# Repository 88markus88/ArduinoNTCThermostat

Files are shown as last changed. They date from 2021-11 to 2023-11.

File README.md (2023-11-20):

# ArduinoNTCThermostat
This project is an Arduino based Thermostat for universal use. I put it together rather quick&dirty since I needed a simple thermostat, and I could not find one that fit my needs...
The project contains the Arduino code and the KiCad files for the board.

I ended up with a rather generic setup, that may be of use to others. The thermostat is intended to be used standalone in 12V or 24 V environments. It's settings for cooling or heating mode, for the target temperature and the hysteresis can be set without recompilation using a bridge (heating/cooling) and DIP switches (target temperature and hysteresis). A relay is fitted that can switch up to 250V and 10A.
A SSD1306 compatible OLED display can be fitted as an option to display detailed information.

## Features:
- Temperature measurement is done via a 10K NTC sensor
- Powered using an efficient DCDC converter (Traco TSR 1-2450E pin compatible to 7805) for operation in range of 7-36 V DC. The thermostat can easily operate in 12 or 24 V installations.
- Set for heating or cooling operation with a bridge
- Set target temperature fron 0 to 254 °C in 2°C steps via DIP switches
- Set hysteresis from 0 to 14 °C in 2°C steps via DIP switches
- 250V 10A relay. PCB design supports up to 10 A
- 2 LEDs: power indicator and switch indicator
- Optional OLED display via I2C

## PCB
The PCB has been designed in Kicad. Kicad files are included in this repository, also the Gerber files that can directly be used to order the PCBs

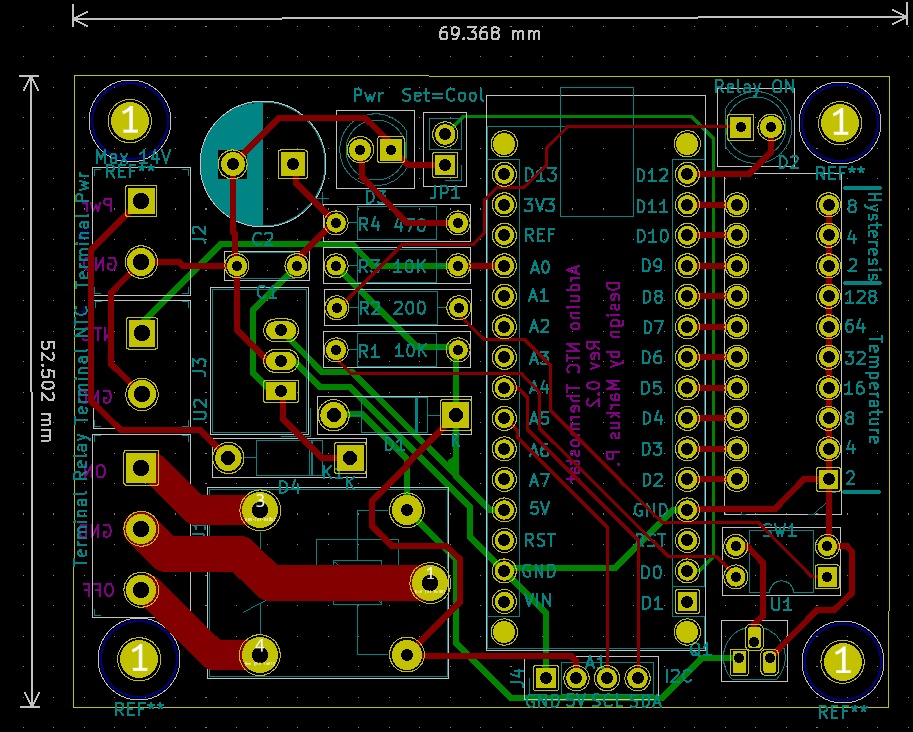
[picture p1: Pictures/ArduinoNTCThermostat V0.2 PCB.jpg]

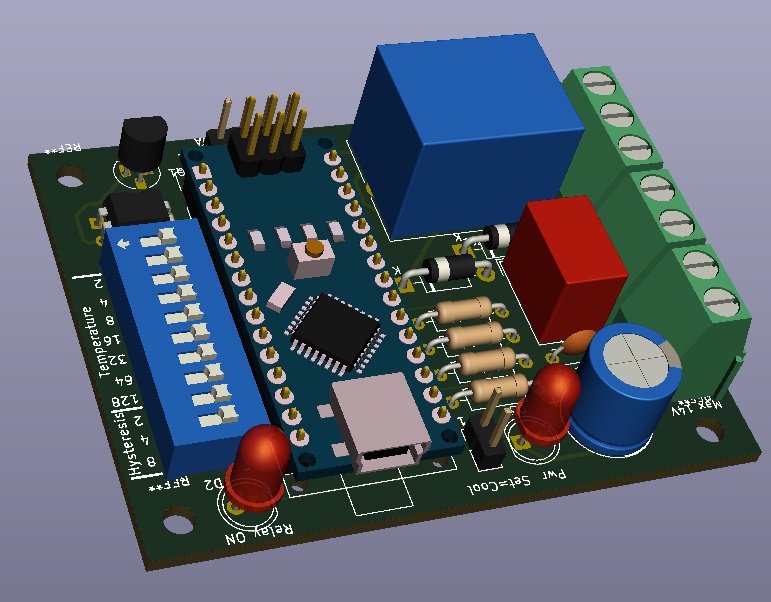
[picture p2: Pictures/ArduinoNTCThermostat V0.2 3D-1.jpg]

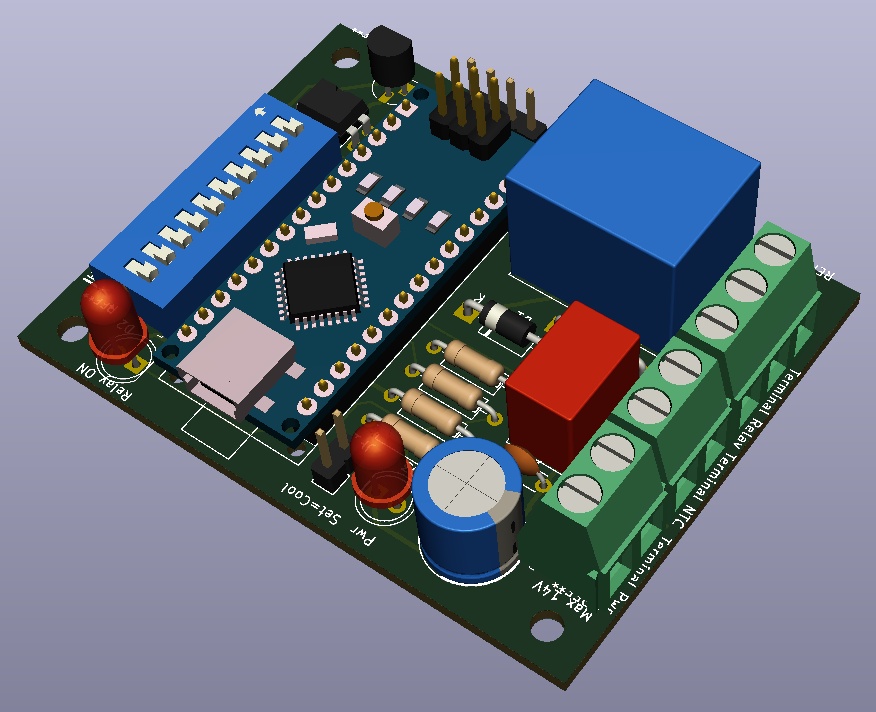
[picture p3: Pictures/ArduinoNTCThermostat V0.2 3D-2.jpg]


## Parts List
- PCB: Gerber files are attached
- Arduino Pro Micro (with socket, if desired)
- Transistor BC547
- Electrolyte Capacitor 47 uF / 25V
- Tantal Capacitor 100 nF
- Opto Coupler LTV 817
- 2 Diodes 1N4001 or 1N4004
- 2 LEDs
- Power via DCDC  Traco TSR 1-2450E, alternatively 7850
- 10x DIP Switch
- Screw Terminals 5.08 mm pitch: 2x 2, 1x 3 connections
- Relay Songle SRD-05VDC-SL-C
- Resistors: 200, 470 and 2 x 10K Ohm
- NTC 10K
- OLED Display with SSD1306 controller (optional)
- Housing

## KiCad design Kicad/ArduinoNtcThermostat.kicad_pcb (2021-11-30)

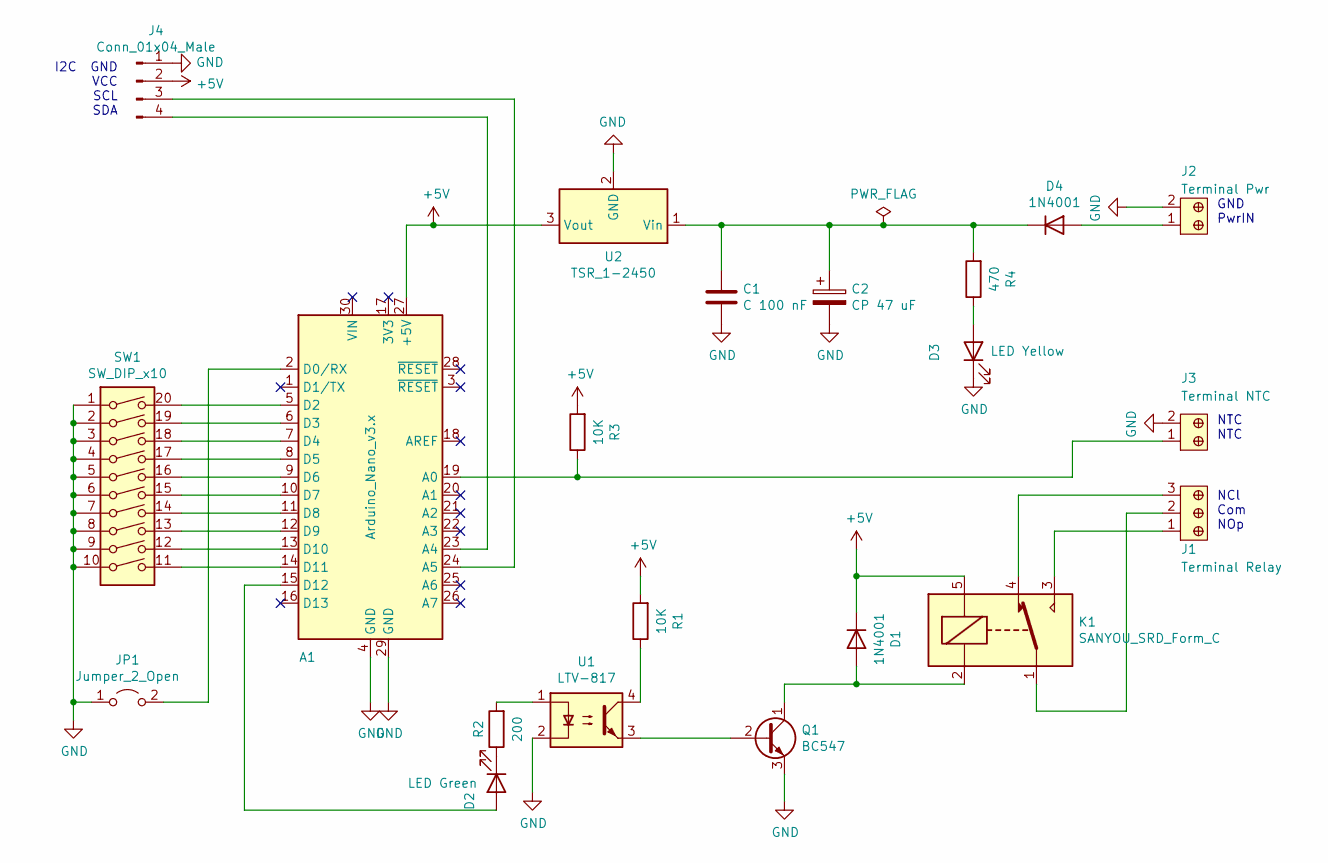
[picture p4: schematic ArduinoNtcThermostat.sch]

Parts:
A1: Arduino_Nano_v3.x; Arduino_Nano_WithMountingHoles
C1: C 100 nF; C_Disc_D4.3mm_W1.9mm_P5.00mm
C2: CP 47 uF; CP_Radial_D10.0mm_P5.00mm
D1, D4: 1N4001; D_DO-41_SOD81_P10.16mm_Horizontal
D2: LED Green; LED_D5.0mm
D3: LED Yellow; LED_D5.0mm
J1: Terminal Relay; TERM_BLOCK_1x3_P5.08MM; MPN OSTTC032162; Digi-Key_PN ED2610-ND
J2: Terminal Pwr; Term_Block_1x2_P5.08MM; MPN OSTTC022162; Digi-Key_PN ED2609-ND
J3: Terminal NTC; Term_Block_1x2_P5.08MM; MPN OSTTC022162; Digi-Key_PN ED2609-ND
J4: Conn_01x04_Male; PinHeader_1x04_P2.54mm_Vertical
JP1: Jumper_2_Open; PinHeader_1x02_P2.54mm_Vertical
K1: SANYOU_SRD_Form_C; Relay_SPDT_SANYOU_SRD_Series_Form_C
Q1: BC547; TO-92_HandSolder
R1, R3: 10K; R_Axial_DIN0207_L6.3mm_D2.5mm_P10.16mm_Horizontal
R2: 200; R_Axial_DIN0207_L6.3mm_D2.5mm_P10.16mm_Horizontal
R4: 470; R_Axial_DIN0207_L6.3mm_D2.5mm_P10.16mm_Horizontal
SW1: SW_DIP_x10; DIP-20_W7.62mm
U1: LTV-817; DIP-4_W7.62mm
U2: TSR_1-2450; Converter_DCDC_TRACO_TSR-1_THT

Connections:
+5V: A1.27 (+5V), D1.1 (K), J4.2, K1.5, R1.2, R3.2, U2.3 (Vout)
GND: A1.4 (GND), A1.29 (GND), C1.2, C2.2, D3.1 (K), J2.2, J3.2, J4.1, JP1.1 (A), Q1.3 (E), SW1.1, SW1.2, SW1.3, SW1.4, SW1.5, SW1.6, SW1.7, SW1.8, SW1.9, SW1.10, U1.2, U2.2 (GND)
unnamed: A1.2 (D0/RX), JP1.2 (B)
unnamed: A1.5 (D2), SW1.20
unnamed: A1.6 (D3), SW1.19
unnamed: A1.7 (D4), SW1.18
unnamed: A1.8 (D5), SW1.17
unnamed: A1.9 (D6), SW1.16
unnamed: A1.10 (D7), SW1.15
unnamed: A1.11 (D8), SW1.14
unnamed: A1.12 (D9), SW1.13
unnamed: A1.13 (D10), SW1.12
unnamed: A1.14 (D11), SW1.11
unnamed: A1.15 (D12), D2.2 (A)
unnamed: A1.19 (A0), J3.1, R3.1
unnamed: A1.23 (A4), J4.4
unnamed: A1.24 (A5), J4.3
unnamed: C1.1, C2.1, D4.1 (K), R4.2, U2.1 (Vin)
unnamed: D1.2 (A), K1.2, Q1.1 (C)
unnamed: D2.1 (K), R2.1
unnamed: D3.2 (A), R4.1
unnamed: D4.2 (A), J2.1
unnamed: J1.1, K1.3
unnamed: J1.2, K1.1
unnamed: J1.3, K1.4
unnamed: Q1.2 (B), U1.3
unnamed: R1.1, U1.4
unnamed: R2.2, U1.1

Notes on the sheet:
I2C GND VCC SCL SDA
NCl Com NOp
NTC NTC
GND PwrIN

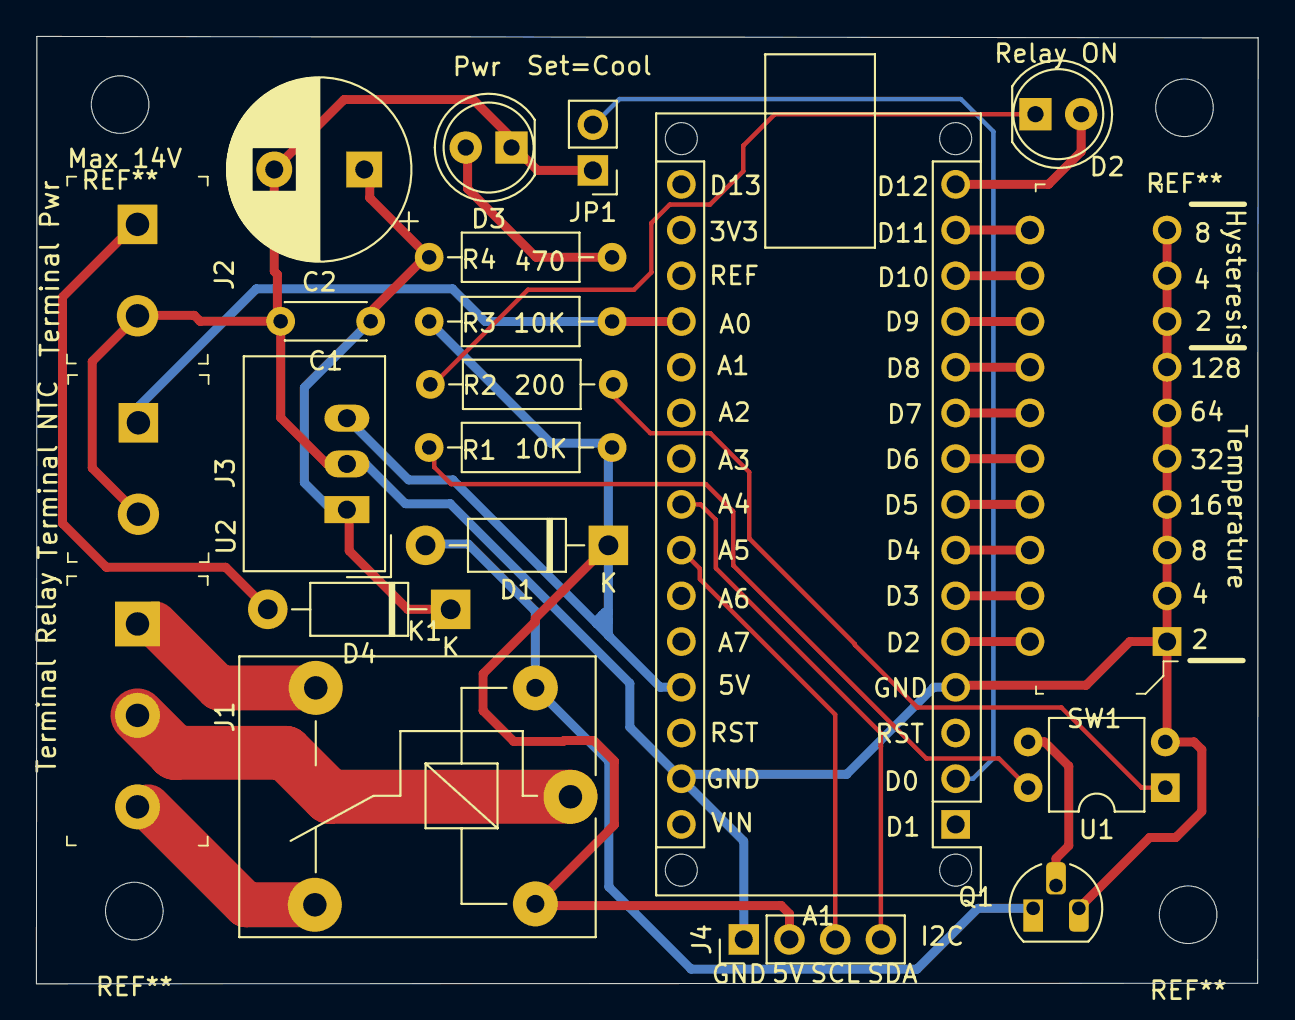
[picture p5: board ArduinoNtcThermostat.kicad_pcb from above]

Board: 2 copper layers, 67.9 x 52.6 mm, 21 parts (0 on the bottom side), 28 nets.

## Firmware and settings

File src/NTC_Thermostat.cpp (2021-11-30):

#define PROGNAME  "NTC_Thermostat.cpp"
#define PROGVERSION "V0.03"
#define PROGDATE "2021-11-10"

#include <Arduino.h>
#include <avr/wdt.h>

#undef isPlotter
#ifdef isPlotter
  #include "Plotter.h"
  Plotter p;
  double x;
#endif

#define isDIPSwitch
// dip switches are used to control the temperature setting for the thermostat
// the values for all set switches are added. e.g. 2&4&6 ON: 2.5+10+40 = 52.5 °C
// same for hysteresis. 8 ON = 5°C, 8&9 ON = 15 °C Hysteresis
#ifdef isDIPSwitch
  // new binary values for PCB
  int noDIPSwitches = 7;  // temperature settings control for switches. 
  int switchArray[7]=   {2, 3, 4,  5,  6,  7,   8};   // digital ports for switches
  double switchValue[7]={2, 4, 8, 16, 32, 64, 128};   // value for these digital ports  
  // old values from prototype
  // int noDIPSwitches = 7;  // temperature settings control for switches. 
  // int switchArray[6]=   {2,   3,  4,  5,  6,  7};   // digital ports for switches
  // double switchValue[6]={2.5, 5, 10, 20, 40, 80};   // value for these digital ports  

  // new binary values for PCB
  // old values from prototype
  int noHysSwitches = 3;               // hysteresis control for heater
  int hysArray[3]=   {9,   10,  11};   // digital ports for switches
  double hysValue[3]={2,    4,   8};   // value for these digital ports  

  #define MODE_HEATING  0       
  #define MODE_COOLING  1
  int switchForMode = 0;               // digital port for switch heating (open) to cooling (closed)
#endif

#define isRelay
#ifdef isRelay  // relais connected to GPIO 12
  #define RELAYPIN1 12 //not 13, that is connected to LED and switched during start
#endif  

// port for a heartbeat LED
#undef isLEDHeartbeat
#ifdef isLEDHeartbeat
  #define HEARTBEATPIN 11
#endif

#define isDisplay
#ifdef isDisplay
  // OLED Display
  // stuff for SSD1306 ASCII library. Used instead of adafruit since better memory usage
  // https://github.com/greiman/SSD1306Ascii 
  #include <Wire.h>
  #include "SSD1306Ascii.h"
  #include "SSD1306AsciiWire.h"
  // 0X3C+SA0 - 0x3C or 0x3D
  #define I2C_ADDRESS 0x3C
  // Define proper RST_PIN if required.
  #define RST_PIN -1
#endif  // isDisplay

#ifdef isDisplay
  // SSD1306ascii - oled object 
  SSD1306AsciiWire oled;
#endif  // isDisplay

// state machine states & variable for heater control
#define stHEATING 1
#define stOVERHEATED 2
#define stFAIL 3
#define stCOOLING 4
#define stOVERCOOLED 5

int heaterState = 0;

// thermostatat mode: heating or cooling
int thermostatMode = 0;      // 0= heating, dip open. 1=cooling, dip closed

// target temperature and hysteresis with defaults
float targetTemp = 28.0;     // when this temp is reached: overheated
float tempHysteresis = 5.0;  // hysteresis: switching back to heating if targetTemp-tempHysteresis

// variables for text output on serial (usb) port
char printstring[120];
char number1[12], number2[12];

/**************************************************!
  @brief    get the actual state of the system: heating or overheated, and set the state accordingly
  @details  is using global variables: 
              heaterState     store the actual state
              targetTemp      thermostat target temperature
              tempHysteresis  temperature hysteresis. switching on again if targetTemperature - tempHysteresis reached
            States:
            stHEATING     : normal heating, relay is on
            stOVERHEATED  : over targetTemp, and not yet below targetTemp-tempHysteresis
            stFAIL        : failure, e.g. NTC sensor broken (open)

  @param    float actTemp
  @note     uses global variables to store information
  @return   int 
***************************************************/
int getHeaterState(float actTemp)
{
  if(thermostatMode == MODE_HEATING)
  {
    switch(heaterState){
      case (stHEATING):
        if(actTemp >= targetTemp)
          heaterState = stOVERHEATED;
        if(actTemp < -300)
          heaterState = stFAIL;
        break;
      case (stOVERHEATED):
        if(actTemp < targetTemp - tempHysteresis)
          heaterState = stHEATING;
        if(actTemp < -300)
          heaterState = stFAIL;  
        break;
      case (stFAIL):
        {
          if(actTemp > -300)  // no longer in fail, go to overheated
            heaterState = stOVERHEATED;
          break;
        }  
      default:
        heaterState = stOVERHEATED;
    } // switch heaterState
  }

  if(thermostatMode == MODE_COOLING)
  {
    switch(heaterState){
      case (stCOOLING):
        if(actTemp <= targetTemp)
          heaterState = stOVERCOOLED;
        if(actTemp < -300)
          heaterState = stFAIL;
        break;
      case (stOVERCOOLED):
        if(actTemp > targetTemp + tempHysteresis)
          heaterState = stCOOLING;
        if(actTemp < -300)
          heaterState = stFAIL;  
        break;
      case (stFAIL):
        {
          if(actTemp > -300)  // no longer in fail, go to overheated
            heaterState = stOVERCOOLED;
          break;
        }  
      default:
        heaterState = stOVERCOOLED;
    } // switch heaterState
  }
  return(heaterState);
}

/**************************************************!
  @brief    get the thermostat mode (heating or cooling) from jumper
  @details  this function evaluates jumper setting to determine the 
            thermostat mode, either for heating (jumper open or for cooling (jumper closed)
            is using global variables: 
              none
  @param   none
  @return  double int mode
***************************************************/
int getThermostatModeFromDIP()
{
  int val,mode;

  val=digitalRead(switchForMode);
  if(val==0)  // jumper is closed
    mode = MODE_COOLING; // cooling
  else  
    mode = MODE_HEATING; // heating

  sprintf(printstring,"PIN: %d Val: %d Thermostat Mode: %d \n", switchForMode, val, mode);
  Serial.print(printstring);

  return(mode);    
}

/**************************************************!
  @brief    get the target temperature in °C from dip switch settings 
  @details  this function evaluates dip switch settings to determine the 
            thermostat target temperature
            is using global variables: 
              switchArray[]     store the dip switch ports used
              switchValue[]     assigns temp values to each dip switch
  @param   none
  @return  double tempTarget: Target temperature for thermostat in °C
***************************************************/
double getTargetTempFromDIP()
{
  int i, val;
  double tempTarget = 0;

  for(i=0;i<noDIPSwitches;i++){
    val = digitalRead(switchArray[i]);
    if(val == 0)
      tempTarget += switchValue[i];
    // dtostrf(switchValue[i],4,2,number1);  
    // sprintf(printstring,"%d %d %s / ",switchArray[i],val, number1);  
    // Serial.print(printstring);
  }
  return(tempTarget);
}

/**************************************************!
  @brief    get the temp hysteresis in °C from dip switch settings
  @details  this function evaluates dip switch settings to determine the 
            temperature hysteresis for the thermostat
            is using global variables: 
              hysArray[]     store the dip switch ports used
              hysValue[]     assigns temp values to each dip switch
  @param   none
  @return  hysTarget: Target Hysteresis in °C
***************************************************/
double getHysteresisFromDIP()
{
  int i, val;
  double hysTarget = 0;

  for(i=0;i<noHysSwitches;i++){
    val = digitalRead(hysArray[i]);
    if(val == 0)
      hysTarget += hysValue[i];
    // dtostrf(hysValue[i],4,2,number1);  
    // sprintf(printstring,"%d %d %s / ",hysArray[i],val, number1);  
    // Serial.print(printstring);
  }
  return(hysTarget);
}


// NTC temperature calculation data
double U_0 = 4.750;     // reference voltage for measurement at Arduino Nano
double R_ref = 10000;  // resistor in series with NTC
double T_0 = 298.15;   // NTC reference temperature: 25°C  
double B = 3977;       // NTC B value//--- calculation routine for temperature from voltage over ntc in mV
/**************************************************!
  @brief    calculation routine for temperature from voltage over ntc in mV
  @details  this function gets the measured voltage across the NTC in mV
            and calculates the temperature in °C from it.
            It uses global variables for the calculation:
            double U_0 = 4.75;     // reference voltage [V] over whole resistor bridge
            double R_ref = 10000;  // resistor in series with NTC in [Ohm]
            double T_0 = 298.15;   // NTC reference temperature in [K]: 25°C  
            double B = 3977;       // NTC B value 
  @param   double U_Meas:   measured voltage at NTC in [mV]
  @return  double T_meas:   measured temperature in [°C]
***************************************************/
double calcTemp(double U_meas)
{
  double T_meas, R_meas;

  R_meas = R_ref/(1000*U_0/U_meas - 1.0);
  if(R_meas < 500000)
    T_meas = (1/(log(R_meas/R_ref)/B + 1/T_0)) - 273.15;
  else
    T_meas = -999;  // error condition if resistance too high, likely broken
  
  #ifndef isPlotter
    dtostrf(R_meas,4,2,number1);    // use this since %f does not work in sprintf on arduino
    dtostrf(T_meas,4,2,number2);    // use this since %f does not work in sprintf on arduino
    sprintf(printstring,"R_meas: %s [Ohm] T_meas %s [°C] ",number1, number2);
    Serial.print(printstring);
  #endif
  return(T_meas);
}

// setup routine
/**************************************************!
  @brief    setup routine
  @details  set serial mode for communiction with terminal
          set pinMOde for analog input from resistor measuring bridge
          prepares plotter using "processing" with listener script and plotter.h lib
          evalates dip switches for target temperature and hysteresis
          sets port for relay, and before that sets it to safe "LOW"
  @param   none
  @return  void
***************************************************/
void setup() {
  int i;

  Serial.begin(115200);
  delay(1000);

  wdt_enable(WDTO_4S);   // Watchdog auf 4 s stellen. http://www.netzmafia.de/skripten/hardware/Arduino/Watchdog/index.html 
  
  pinMode(A0, INPUT);   // pin for analog input from resistor bridge with NTC

  #ifdef isPlotter
    p.Begin();
    p.AddTimeGraph( "Temp Graph [3600 points]", 3600, "NTC Temp [C]", x );
  #endif

  #ifdef isDIPSwitch
    // set input digital ports for target temperature dip switches. 
    for(i=0;i<noDIPSwitches;i++){
      delay(10);
       pinMode(switchArray[i], INPUT_PULLUP);
      }
    // set input digital ports for hysteresis dip switches. 
    for(i=0;i<noHysSwitches;i++){
      delay(10);
       pinMode(hysArray[i], INPUT_PULLUP);
      }  
    // set input digital port for heating / cooling mode
    pinMode(switchForMode, INPUT_PULLUP);
  #endif

  // set digital port as output for Relay
  #ifdef isRelay
    digitalWrite(RELAYPIN1, LOW);   // vor dem Modus setzen auf LOW, um relais klackern zu vehindern
    pinMode(RELAYPIN1,OUTPUT);
    delay(10);
  #endif

  // Set digital Output as output for LED
  #ifdef isLEDHeartbeat
    pinMode(HEARTBEATPIN, OUTPUT); // Digital-Pin 0 as input
  #endif   

  #ifdef isDisplay
    // ssd1306ascii stuff
    Wire.begin();
    Wire.setClock(400000L);

    #if RST_PIN >= 0
      oled.begin(&Adafruit128x64, I2C_ADDRESS, RST_PIN);
    #else // RST_PIN >= 0
      oled.begin(&Adafruit128x64, I2C_ADDRESS);
    #endif // RST_PIN >= 0
    oled.setFont(System5x7);
    oled.clear();
  #endif 
} // setup

// ========= Main LOOP =========
/**************************************************!
  @brief    ========= Main LOOP =========
  @details  main loop            
  @param   none
  @return  void
***************************************************/
void loop() {
  int U_read, i;
  double tempC, U_ntc, U_vcc, tmp=0.0;

  // test
  /*
  digitalWrite(RELAYPIN1, HIGH);
  delay(200);
  digitalWrite(RELAYPIN1, LOW);
  */

  wdt_reset(); // keep watchdog happy

  // get thermostat mode from switch. can be MODE_HEATING or MODE_COOLING
  thermostatMode = getThermostatModeFromDIP();
  // sprintf(printstring,"Thermostat Mode: %d \n", thermostatMode);
  // Serial.print(printstring);

  // get the target temperature and hysteresis settings
  targetTemp = getTargetTempFromDIP();
  dtostrf(targetTemp,4,1,number1);
  tempHysteresis = getHysteresisFromDIP();
  dtostrf(tempHysteresis,4,1,number2);
  sprintf(printstring,"Target: %s [C] Hysteresis: %s [C] --- ", number1, number2 );
  #ifndef isPlotter
    Serial.print(printstring);
  #endif  

  // read analog value on A0
  U_read = 0;
  for(i=0; i<10;i++)
    U_read += analogRead(A0);
  tmp = (float)U_read/10;  
  U_vcc = U_0;                // Actual Arduino 5V supply voltage in mV
  U_ntc= 1000*(U_vcc * (tmp)/1023);  // ntc voltage in mV. Basis: VCC=4.750 V. (Was number 4750.0)
  dtostrf(tmp,4,2,number1);    // use this since %f does not work in sprintf on arduino
  dtostrf(U_ntc,4,2,number2);    // use this since %f does not work in sprintf on arduino
  sprintf(printstring,"U_read: %s U_ntc: %s  [mV] \n", number1, number2);
  #ifndef isPlotter
    Serial.print(printstring);
  #endif  

  tempC = calcTemp(U_ntc);
  if(tempC<-300){    // error condition: -999
    sprintf(printstring," NTC broken, high resitance ");
    #ifndef isPlotter
      Serial.print(printstring);
    #endif  
  }

  // get and update the heater state in state machine
  getHeaterState(tempC);
  #ifndef isPlotter
    sprintf(printstring," Thermostat mode: %d Heater state: %d  \n",thermostatMode, heaterState);
    Serial.print(printstring);
  #endif  

  // set LED according to heater state
  #ifdef isLEDHeartbeat
    if(heaterState == stHEATING || heaterState==stCOOLING)
      digitalWrite (HEARTBEATPIN, HIGH);
    else
      digitalWrite (HEARTBEATPIN, LOW); 
  #endif  

  // set relay according to heater state
  #ifdef isRelay
    if(heaterState == stHEATING || heaterState==stCOOLING)
      digitalWrite(RELAYPIN1, HIGH);
    else
      digitalWrite(RELAYPIN1, LOW);
  #endif

  // output to OLED display
  #ifdef isDisplay
    // stuff for ssd1306ascii
    // oled.clear();
    oled.setCursor(0,0);
    oled.setInvertMode(true);
    if(thermostatMode == MODE_HEATING)
      sprintf(printstring," Thermostat: Heating  ");
    else
      sprintf(printstring," Thermostat: Cooling  "); 
    oled.print(printstring);
    oled.setInvertMode(false);

    oled.setCursor(0,2);
    dtostrf(targetTemp,4,1,number1); 
    dtostrf(tempHysteresis,4,1,number2); 
    sprintf(printstring,"Limit:%s Hys:%s C  ",number1,number2);
    // Serial.print(printstring);
    oled.print(printstring);

    oled.setCursor(0,3);
    dtostrf(U_ntc,4,2,number1); 
    sprintf(printstring,"U: %s [mV]   ",number1);
    // Serial.print(printstring);
    oled.print(printstring);

    oled.setCursor(0,5);
    oled.set2X();
    dtostrf(tempC,5,2,number1); 
    sprintf(printstring," %s [C]   ",number1);
    // Serial.print(printstring);
    oled.print(printstring);
    oled.set1X();
    
    oled.setCursor(0,7);
    if(heaterState==stHEATING)    
      sprintf(printstring," htrState: %d HEATING   ",heaterState);
    if(heaterState==stOVERHEATED) 
      sprintf(printstring," htrState: %d OVERHEAT  ",heaterState);
    if(heaterState==stCOOLING)    
      sprintf(printstring," htrState: %d COOLING   ",heaterState);
    if(heaterState==stOVERCOOLED) 
      sprintf(printstring," htrState: %d OVERCOOL  ",heaterState);  
    if(heaterState==stFAIL) 
      sprintf(printstring," htrState: %d FAIL      ",heaterState);
    // sprintf(printstring,"htrState: %d OVERHEAT   ",heaterState);
    // Serial.print(printstring);
    if(heaterState==stHEATING || heaterState==stCOOLING)  
      oled.setInvertMode(true);
    oled.print(printstring);
    oled.setInvertMode(false);


  #endif  

  #ifdef isPlotter
    // x = 10*sin( 2.0*PI*( millis() / 5000.0 ) );
    x = tempC;
    p.Plot(); // usually called within loop()
  #endif

  delay(900);
}

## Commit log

2021-11-30 Initial Commit of Arduino NTC Thermostat - V0.03
2021-11-30 Initial Commit with V0.03
    [ArduinoNtcThermostat-B_Cu.gbr, ArduinoNtcThermostat-B_Mask.gbr, ArduinoNtcThermostat-B_Paste.gbr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]
2021-12-01 Pictures of PCB added
2021-12-01 Update README.md
    Added PCB pictures to Readme.md
2022-02-12 Updated ESP32 platform to 3.5.0 (still with Arduino 1.0.6)
